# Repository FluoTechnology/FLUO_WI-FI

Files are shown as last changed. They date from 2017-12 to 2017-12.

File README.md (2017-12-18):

<p align="left">

</p>

## FLUO WI-FI

<p align="center">

</p>

[*FLUO WI-FI (V01)*](http://fluotechnology.co.uk/product/fluo-wi-fi/)

The FLUO WI-FI is the best board to to create your own IoT solution. It is a microcontroller board based on the ATmega644p 
by ATMEL (MICROCHIP) that support Arduino Ecosystem and the ESP32 module by ESPRESSIF that enables Wi-Fi and Bluetooth Low Energy (BLE).

Repository Contents
-------------------
* **/Documentation** - Data sheets, Pinout, additional product information
* **/Hardware** - EAGLE design files (.brd, .sch)
* **/Production** - Gerber files
* **/Warranty&Declaration** - Declarations documents and warranty 

License Information
-------------------

This product is _**open source**_! 

Please review the LICENSE.md file for license information. 

If you have any questions or concerns on licensing, please contact support@fluotechnology.co.uk.

Distributed as-is; no warranty is given.

  *With* :heart: *from the FLUO Team.*

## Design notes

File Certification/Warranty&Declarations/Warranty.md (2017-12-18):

##FLUO TECHNOLOGY DECLARATIONS

Fluo Technology products intended for sale and use in worldwide markets comply with the applicable international requirements 
for product safety, electromagnetic compatibility (EMC), essential safety & usage information, WEEE, RoHS, 
quality, and for use in hazardous locations. 
Products delivered into the European Economic Area (EEA) comply with the directives of the European Community (EC). 
Products delivered into North America comply with their respective directives. 
The products bears CE and/or FCC marks which is tested and certified by Arduino to comply with the EC and/or USA directives.

###SAFETY

All boards are labelled with the FCC and CE logo, as they meet the electromagnetic compatibility standards set in 
their respective jurisdictions. Arduino/Genuino products meet the essential requirements 
of EU Directive 2001/95/CE General directive on products safety and Directive 93/68/CE.

###FCC COMPLIANCE

This device complies with Part 15 of the FCC Rules. Operation is subject to the following two conditions: 
(1) this device may not cause harmful interference, and (2) 
this device must accept any interference received, including interference that may cause undesired operation.

###NOTE

This equipment has been tested and found to comply with the limits for a Class B digital device, pursuant 
to part 15 of the FCC Rules. These limits are designed to provide reasonable protection against harmful 
interference in a residential installation. This equipment generates, uses and can radiate radio frequency 
energy and, if not installed and used in accordance with the instructions, may cause harmful interference 
to radio communications. However, there is no guarantee that interference will not occur in a particular 
installation. If this equipment does cause harmful interference to radio or television reception, which can 
be determined by turning the equipment o and on, the user is encouraged to try to correct the interference 
by one or more of the following measures:
→ Reorient or relocate the receiving antenna;
→ Increase the separation between the equipment and receiver;
→ Connect the equipment into an outlet on a circuit different from that to which the receiver is connected;
→ Consult the dealer or an experienced radio/ TV technician for help.
The following parties are responsible for the compliance of radio frequency equipment with the applicable standards: in the case of equipment subject to authorization under the verification procedure, the manufacturer or, in the case of imported equipment, the importer. If subsequent to manufacture and importation, the radio frequency equipment is modified by any party not working under the authority of the responsible party, the party performing the modification becomes the new responsible party.

###TESTING

Products are subject to triple testing to make sure they are not faulty:
→ First, printed circuit boards are thoroughly tested for short circuits and open connections.
→ Then, boards are powered (and, in products containing a microcontroller, the bootloader is programmed) to check there 
are no macroscopic problems preventing the board from turning on.
→ Finally, the most in-depth test: the board is placed into a custom bed of nails tester, 
and programmed by a test program, which checks its overall functionality.
All boards are tested to meet USA and EU consumer safety, health and environmental requirements.

##LIMITED CONVENTIONAL WARRANTY
 
1.1 In addition to the legal warranty provided by the mandatory provisions of the applicable laws,  FLUO Technology hereby conventionally warrants that its products conform to the speciﬁcations indicated on the packaging of the product (the “Specifications”). This conventional warranty lasts for one (1) from the date of the sale.

FLUO Technology shall not be liable for any defects that are caused by neglect, misuse, improper use or mistreatment by the Customer, including improper installation or testing, or for any products that have been altered or modiﬁed in any way by the Customer. Moreover, FLUO Technology shall not be liable for and does not guarantee the results that the Customer intends to obtain by using / installing on other products the design / speciﬁcations of FLUO Technology’s products. Since the products represent an open source to be used by their purchasers for prototyping / designing / developing other products, the testing and other quality control techniques are carried out only to the extent FLUO Technology deems useful.

1.2 In order to be entitled to avail of this conventional warranty, the Customer shall (i) previously raise a claim directly through the website “fluotechnology.co.uk”, (ii) carry out the preliminary checking procedures on the products indicated therein and, if the problem persists, (iii) return the allegedly defective product to the point of sale where the Customer has purchased it:  all the foregoing within the essential terms of fourteen (14) days from the discovery of the alleged defects. If FLUO Technology ascertains that the above procedure has been timely and correctly carried out by the Customer and that the returned products actually fail to conform to the Specifications warranty set forth above and that, therefore, this conventional warranty applies, FLUO Technology's sole liability shall be to replace such products at its sole costs and expenses within a reasonable time. FLUO Technology’s liability shall be limited to products that are determined by FLUO Technology not to conform to  the  Specifications. Replaced products shall be warranted for a new full conventional warranty period.
 
1.3 EXCEPT AS SET FORTH ABOVE, PRODUCTS ARE PROVIDED "AS IS" AND "WITH ALL FAULTS". FLUO Technology DISCLAIMS ALL OTHER CONVENTIONAL WARRANTIES, EXPRESS OR IMPLIED, REGARDING PRODUCTS, INCLUDING, BUT NOT LIMITED TO, ANY IMPLIED WARRANTIES OF MERCHANTABILITY OR FITNESS FOR A PARTICULAR PURPOSE.
 
1.4 The Customer agrees that prior to using any systems that include FLUO Technology products, the Customer  shall test at their own risk and liability such systems and the functionality of the products as used in such systems.
 
FLUO Technology may provide free of charge some suggestions on the technical possibilities, applications or design customization of its products, as well as of the relative  quality characterization, reliability data or other suggestions. The Customer acknowledges and agrees that providing these suggestions shall not expand or otherwise alter FLUO Technology’s warranties, as set forth above, and that no additional obligations or liabilities shall arise from FLUO Technology considering that it providesing such simple suggestions without entering into the merits of the specific uses of its products that each purchaser intends to make.
 
1.5 FLUO Technology products are not authorized nor suitable for use in safety-critical applications where a failure of the FLUO Technology product would reasonably be expected to cause severe personal injury or death. Safety-critical applications include, without limitation, life support devices and systems, equipment or systems for the operation of nuclear facilities and weapons systems. FLUO Technology products are neither designed nor intended for use in military or aerospace applications or environments, nor for automotive applications or the automotive environment. The Customer acknowledges and agrees that any such prohibited use of FLUO Technology products is solely at the Customer’s risk.

1.6 The Customer acknowledges and agrees that the Customer is the sole responsible for compliance with all legal, regulatory and safety-related requirements concerning any use of FLUO Technology products in the Customer’s application, notwithstanding any applications-related information or support that may be provided by FLUO Technology.
 
2. Consequential Damages Waiver.
 
In no event shall FLUO Technology be liable to the Customer or any third parties for any special, collateral,  indirect, punitive, incidental, consequential or exemplary damages in connection with or arising out of the products provided hereunder, regardless of whether FLUO Technology has been advised of the possibility of such damages. This section will survive the termination of the warranty period.

3. Changes to Speciﬁcations.
 
FLUO Technology may make changes to Specifications and products’ descriptions on its website at any time, without notice. Since the products constitute an open source in continuous development and implementation, the Customer must not rely on the absence or characteristics of any features or instructions marked "reserved“ or "undeﬁned". FLUO Technology reserves these for future deﬁnition and shall have no responsibility whatsoever for conﬂicts or incompatibilities arising from future changes to the above. The product information on the website or materials is subject to change without notice. Do not ﬁnalize a product design/technical  specifications with the above said information.

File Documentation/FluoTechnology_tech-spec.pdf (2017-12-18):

Fluo Technology provides a device platforms that enables users to quickly and easily build, connect and control their IoT applications.
We are a young startup company made in UK but with worldwide view.

The Fluo WiFi creates a synergy between
the world of Things and the world of the Internet,
and allows users to interact with it in the way
Vmore simplest possible.

We give the opportunity to people as possible to have access to the world of IoT, and to be able to easily create their own IoT application.

Giving space to their creativity.
Making friendly technologies
Provide them with a product design
Providing them with the latest technology and making it simple. Create a beginner open IoT community.
Allow them to participate in the Industry 4.0 revolution

## Simplifying IoT

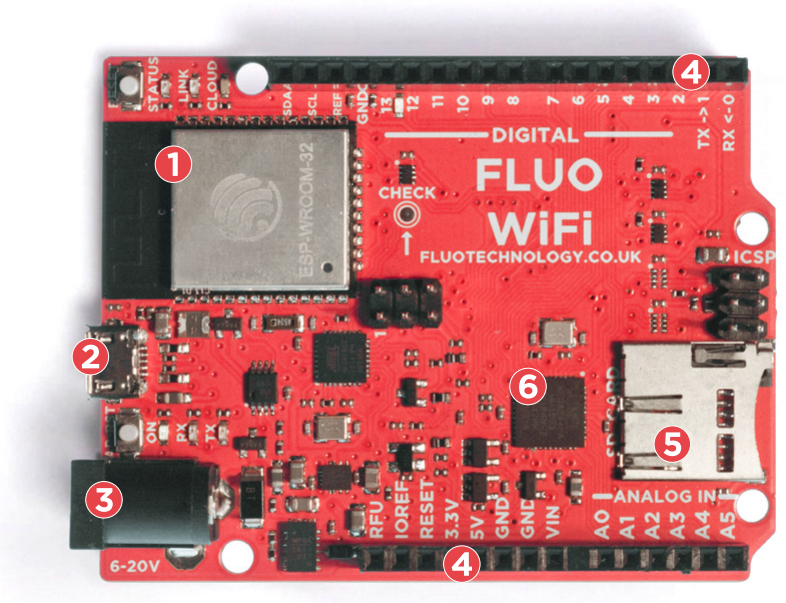
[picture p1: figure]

USB MICRO

POWER Jack 6-20 V

connectors for

arduinio shield r3

sd card
connector

micro controller

wI-FI + BLUETOOTH
LOW ENERGY

2

3

4

5

6

1

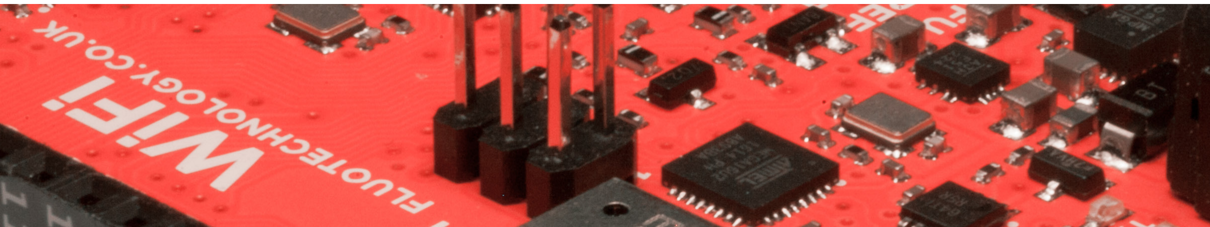
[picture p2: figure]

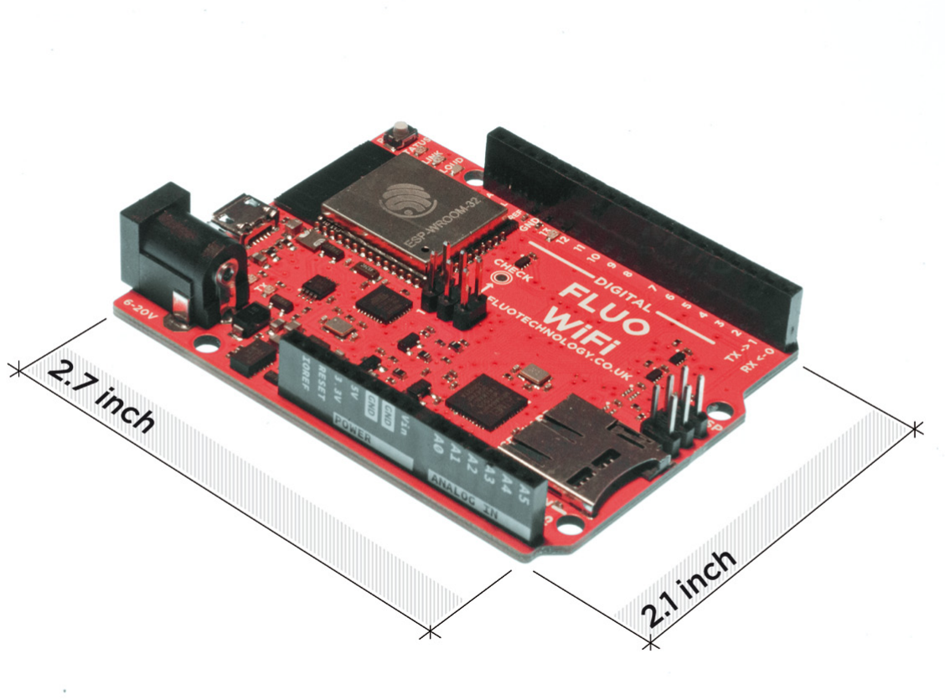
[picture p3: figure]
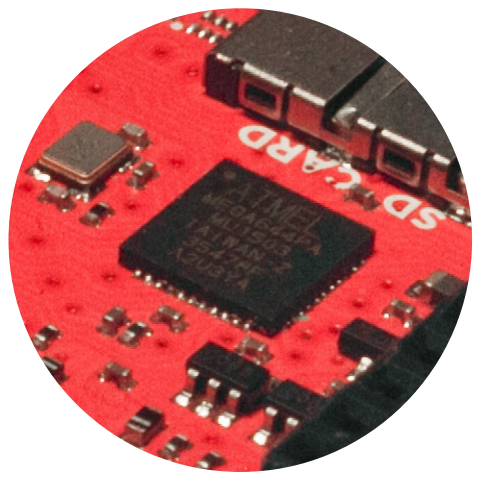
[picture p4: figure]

CPU Name | Atmega 644p

IO MICROCONTROLLER

Architecture | Atmel AVR 8-bit
Core Clock | 16 MHz
SRAM | 4 KBytes
Flash Memory | 64 KBytes
GPIO - Program I/O | 32 (but used only 20)
Interface | SPI-I2C-UART
Operating Voltage | 5V
Connectivity | WiFi 802.11 class BGN/ Bluetooth 4.0 LE

FLUO WiFi TECH SPECS

Wire Interface | USB micro (programmming, debugging, wired connection)
Power IN (real) | 6-20 V
Arduino compatible PIin Headers | R3
Operating Voltage | 5 V
Arduino Shield compatibility | 100%
Power Consumption | 250 mA (estimated)
Size | 2.1”X2.7”
Weight | 0.060 Kg
CPU Name | Espressif esp32

CONNECTIVITY PROCESSOR
(WROOM32 Module)
Architecture | dual core system (Xtensa lx6)
Core Clock | 160 MHz + 160 MHz
SRAM | 520 KB
Flash Memory | 16 MByte
Bluetooth | Legacy and Low Energy
WiFi | 802.11 class BGN

150.0 mbps data rate with ht 40 (49 mhz channel width, 400 ns guard interval, 1 spatial stream, 64-QASM, 5/6 coding rate)

Hardware accelerated encryption (security data)

AES / SHA2 / Elliptical Curve Cryptography / RSA-4096

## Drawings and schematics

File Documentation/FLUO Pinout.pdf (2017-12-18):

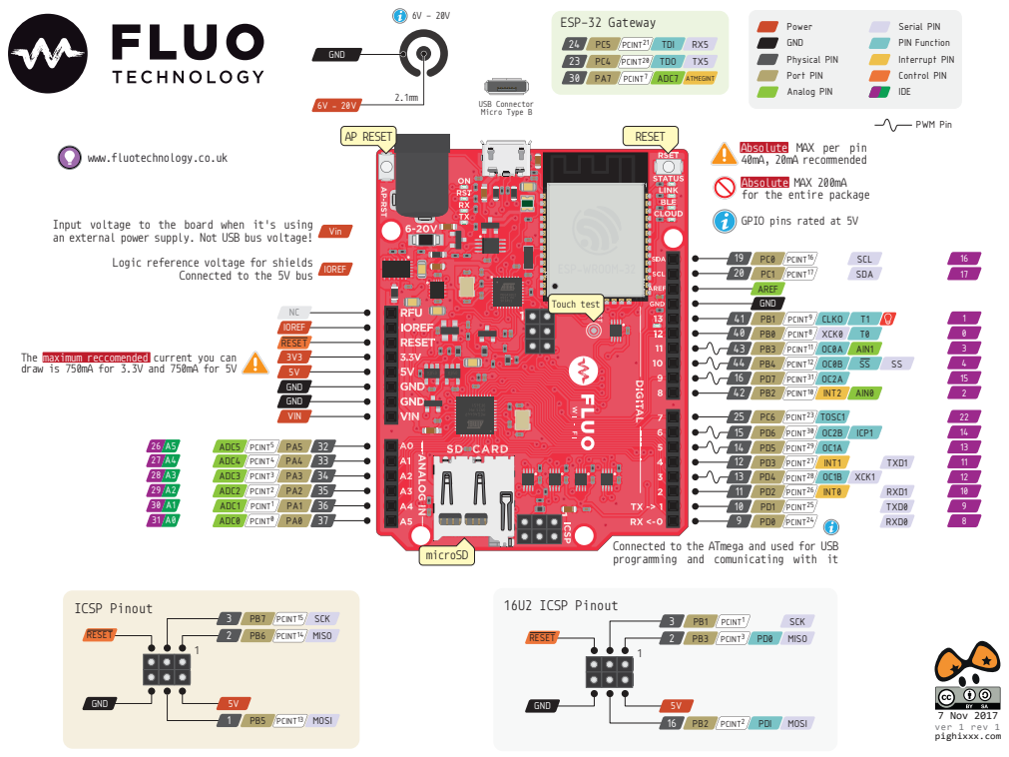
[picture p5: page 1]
GND; USB Connector; Micro Type B; RESET; Touch test; microSD; AP RESET; Vin; IOREF; VIN; PCINT; PA5 ADC5; ADC4 PCINT⁴ PA4 33; PA3 ADC3; PA2 ADC2; PA1 ADC1; PA0 ADC0; PC0 PCINT 19; SCL; PC1 PCINT 20; SDA; AREF; PB1 PCINT 41; PB0 PCINT 40; PD7 PCINT³¹ 16; PB4 PCINT 44; PB2 PCINT 42; 10 INT2 SCK; CLKO XCK0; AIN0; PB3 PCINT 43; 11 OC0A AIN1; ICSP Pinout; PB7 PCINT 3; 15 SCK; PB6 PCINT 2; 14 MISO; PB5 PCINT 1; 13 MOSI; 16U2 ICSP Pinout; PB2 PCINT 16; PDI; MOSI; PB3 PCINT 2; PD0 MISO; PB1 PCINT 3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

Absolute MAX per pin
40mA, 20mA recoended
Absolute MAX 200mA
for the entire package

www.fluotechnology.co.uk

GPIO pins rated at 5V

Input voltage to the board when it's using
an external power supply. Not USB bus voltage!

IOREF Logic reference voltage for shields

Connected to the 5V bus

The maximum reccomended current you can
draw is 750mA for 3.3V and 750mA for 5V

Connected to the ATmega and used for USB
prograing and comunicating with it

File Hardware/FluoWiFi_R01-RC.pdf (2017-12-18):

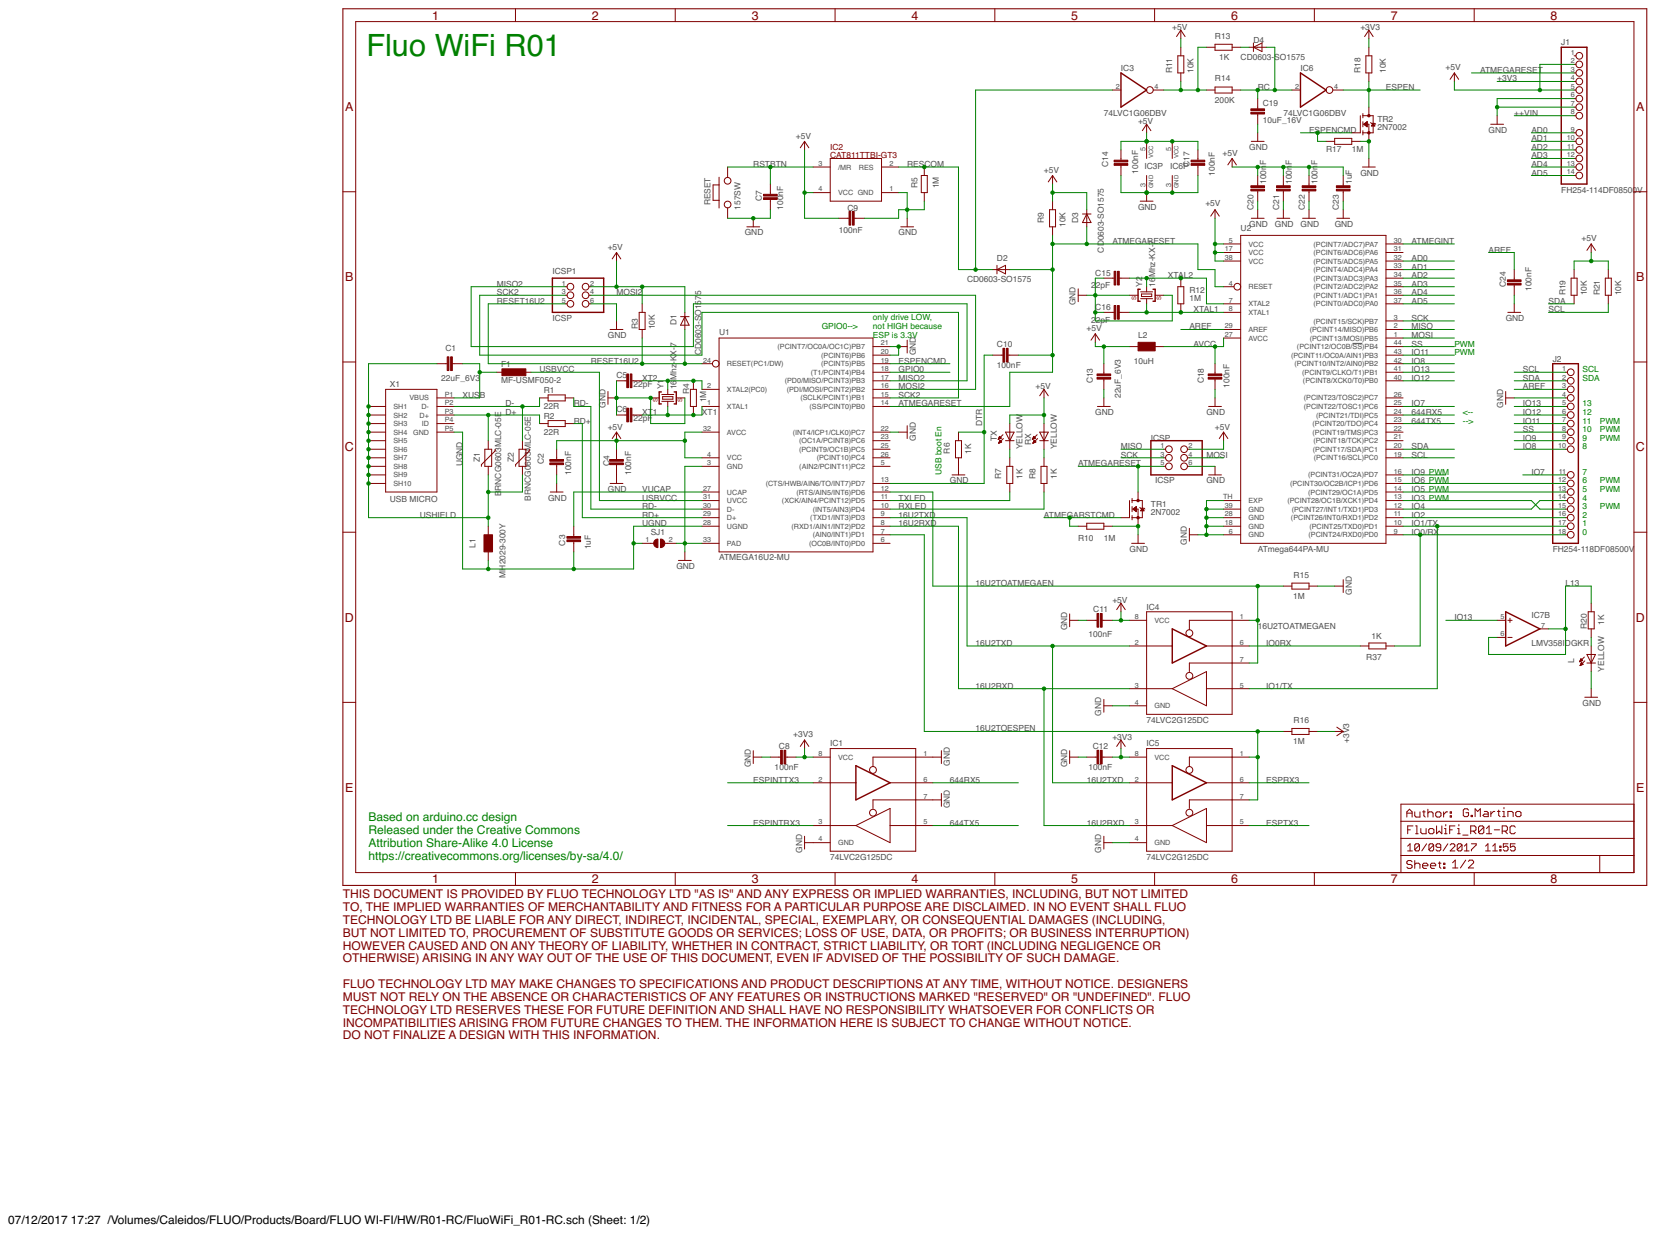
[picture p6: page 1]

only drive LOW, not HIGH because ESP is 3.3V

GND GND

Based on arduino.cc design
Released under the Creative Commons
Attribution Share-Alike 4.0 License
https://creativecommons.org/licenses/by-sa/4.0/

THIS DOCUMENT IS PROVIDED BY FLUO TECHNOLOGY LTD "AS IS" AND ANY EXPRESS OR IMPLIED WARRANTIES, INCLUDING, BUT NOT LIMITED
TO, THE IMPLIED WARRANTIES OF MERCHANTABILITY AND FITNESS FOR A PARTICULAR PURPOSE ARE DISCLAIMED. IN NO EVENT SHALL FLUO
TECHNOLOGY LTD BE LIABLE FOR ANY DIRECT, INDIRECT, INCIDENTAL, SPECIAL, EXEMPLARY, OR CONSEQUENTIAL DAMAGES (INCLUDING, BUT NOT LIMITED TO, PROCUREMENT OF SUBSTITUTE GOODS OR SERVICES; LOSS OF USE, DATA, OR PROFITS; OR BUSINESS INTERRUPTION)

HOWEVER CAUSED AND ON ANY THEORY OF LIABILITY, WHETHER IN CONTRACT, STRICT LIABILITY, OR TORT (INCLUDING NEGLIGENCE OR
OTHERWISE) ARISING IN ANY WAY OUT OF THE USE OF THIS DOCUMENT, EVEN IF ADVISED OF THE POSSIBILITY OF SUCH DAMAGE. FLUO TECHNOLOGY LTD MAY MAKE CHANGES TO SPECIFICATIONS AND PRODUCT DESCRIPTIONS AT ANY TIME, WITHOUT NOTICE. DESIGNERS

MUST NOT RELY ON THE ABSENCE OR CHARACTERISTICS OF ANY FEATURES OR INSTRUCTIONS MARKED "RESERVED" OR "UNDEFINED". FLUO
TECHNOLOGY LTD RESERVES THESE FOR FUTURE DEFINITION AND SHALL HAVE NO RESPONSIBILITY WHATSOEVER FOR CONFLICTS OR
INCOMPATIBILITIES ARISING FROM FUTURE CHANGES TO THEM. THE INFORMATION HERE IS SUBJECT TO CHANGE WITHOUT NOTICE. DO NOT FINALIZE A DESIGN WITH THIS INFORMATION.

07/12/2017 17:27 /Volumes/Caleidos/FLUO/Products/Board/FLUO WI-FI/HW/R01-RC/FluoWiFi_R01-RC.sch (Sheet: 1/2)

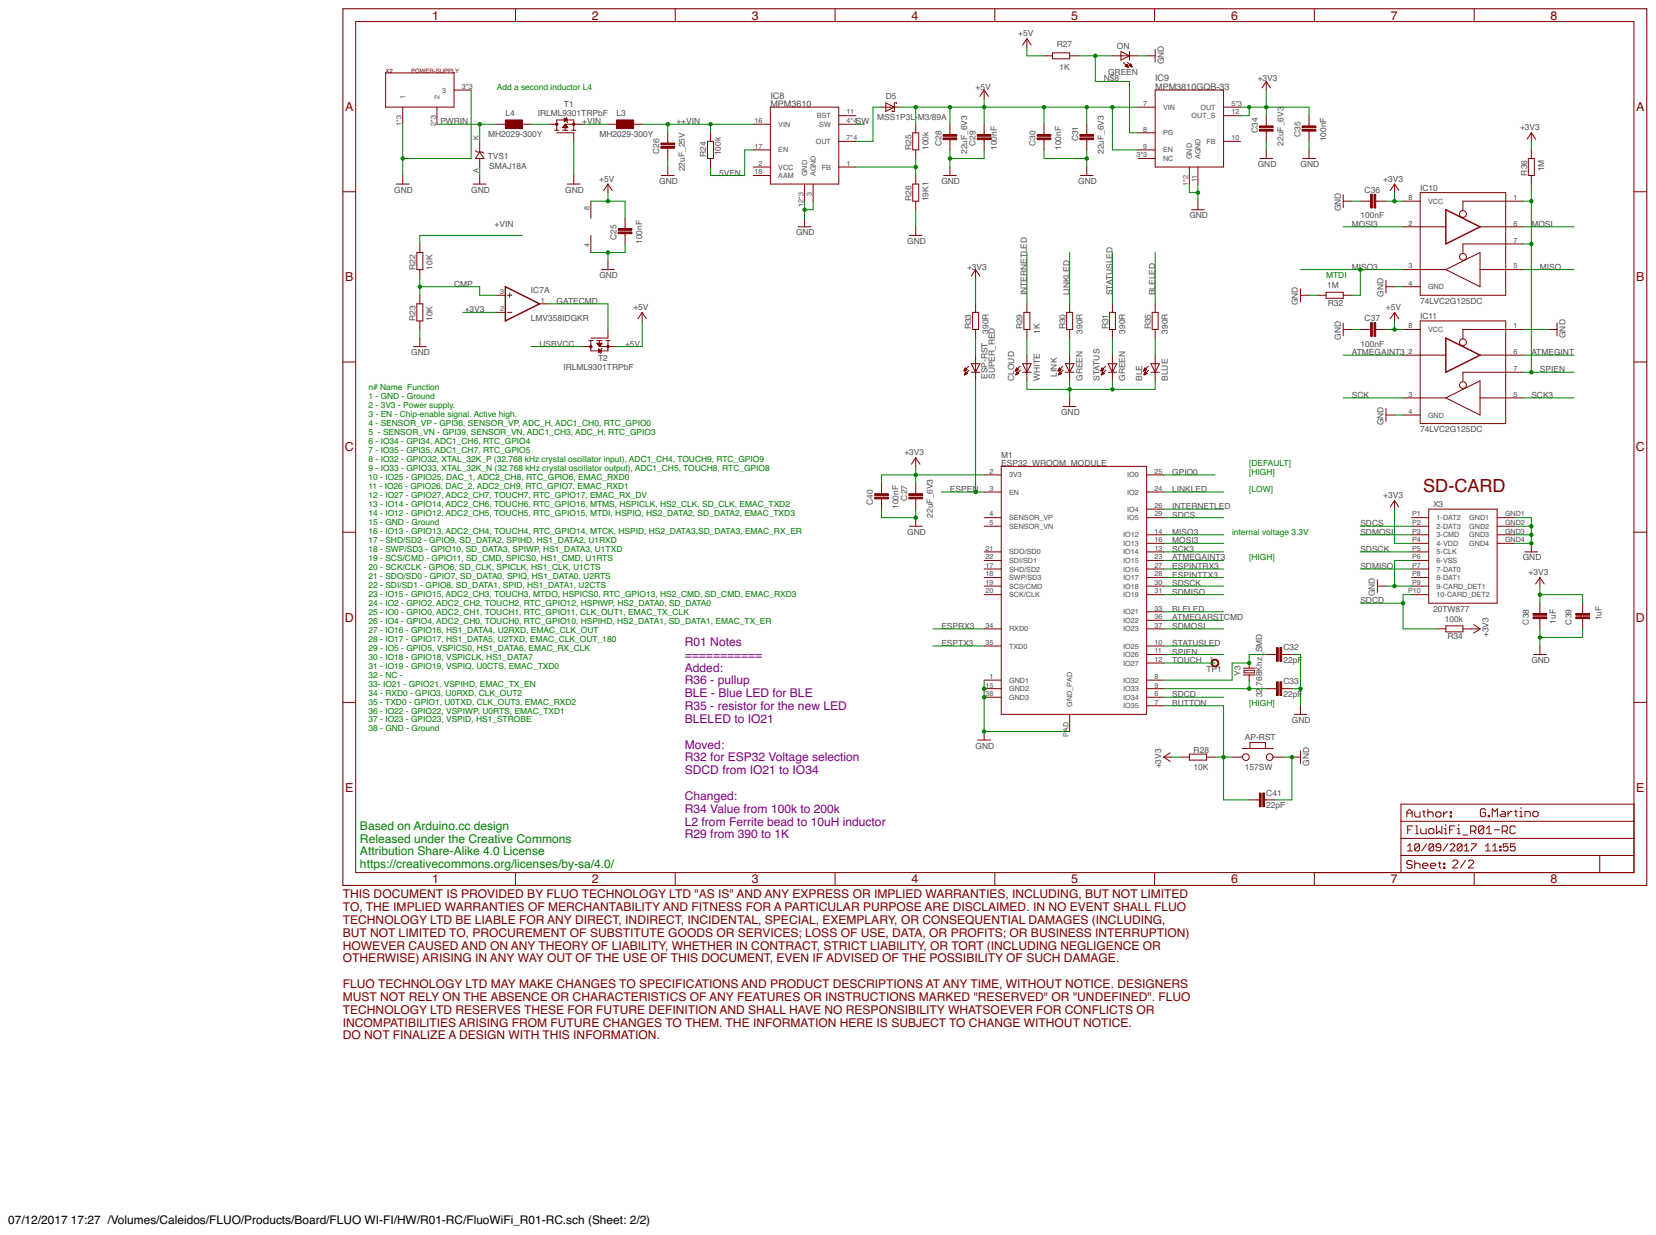
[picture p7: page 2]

GND GND

n# Name Function
1 - GND - Ground
2 - 3V3 - Power supply. 3 - EN - Chip-enable signal. Active high. 4 - SENSOR_VP - GPI36, SENSOR_VP, ADC_H, ADC1_CH0, RTC_GPIO0

R36 - pullup
BLE - Blue LED for BLE
R35 - resistor for the new LED
BLELED to IO21

Changed:
R34 Value from 100k to 200k
L2 from Ferrite bead to 10uH inductor
R29 from 390 to 1K

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

07/12/2017 17:27 /Volumes/Caleidos/FLUO/Products/Board/FLUO WI-FI/HW/R01-RC/FluoWiFi_R01-RC.sch (Sheet: 2/2)

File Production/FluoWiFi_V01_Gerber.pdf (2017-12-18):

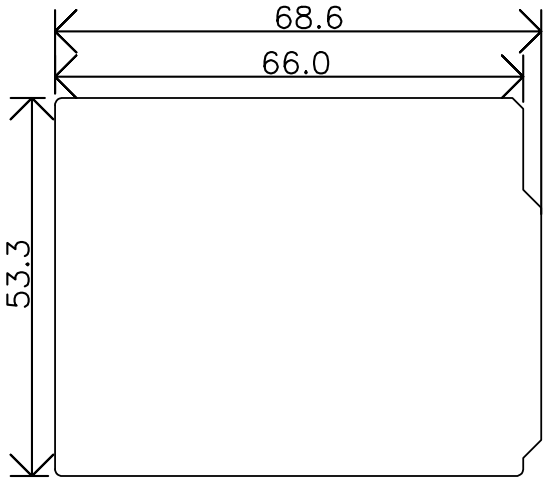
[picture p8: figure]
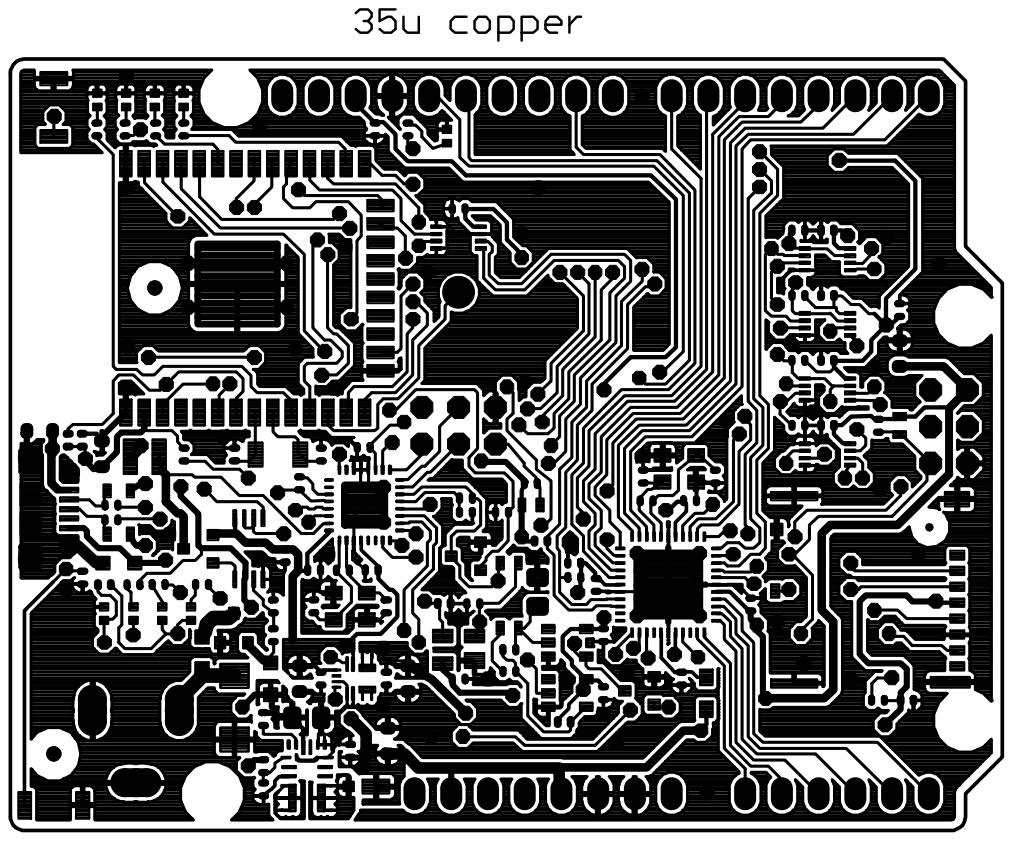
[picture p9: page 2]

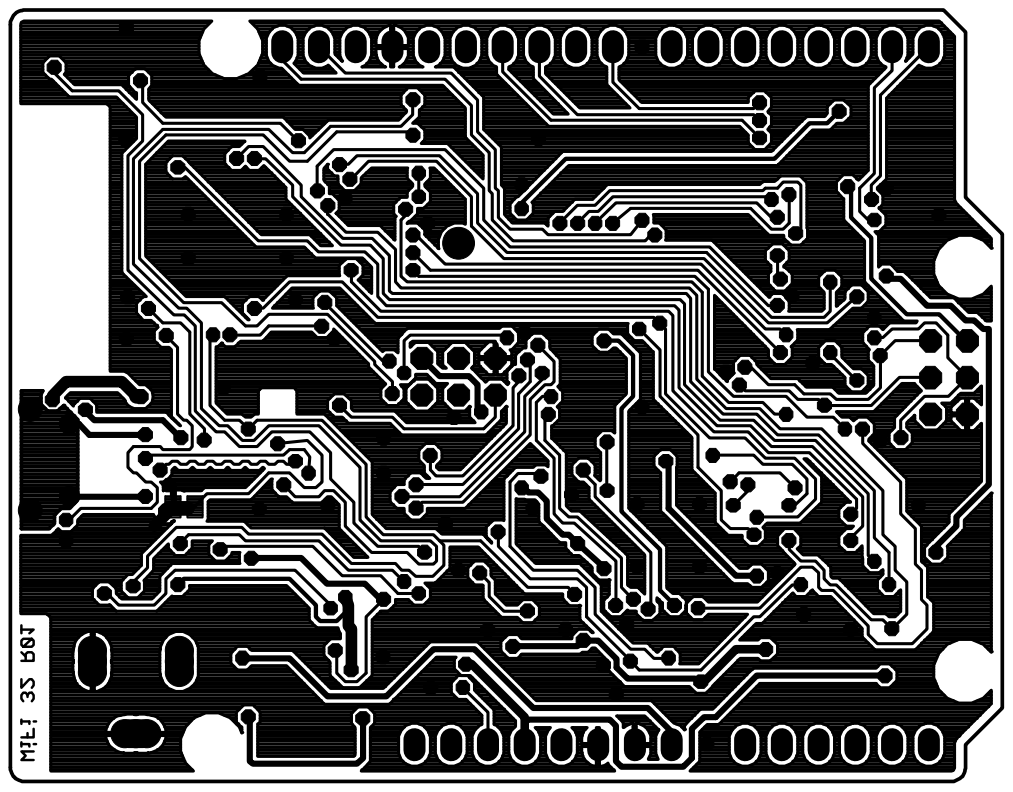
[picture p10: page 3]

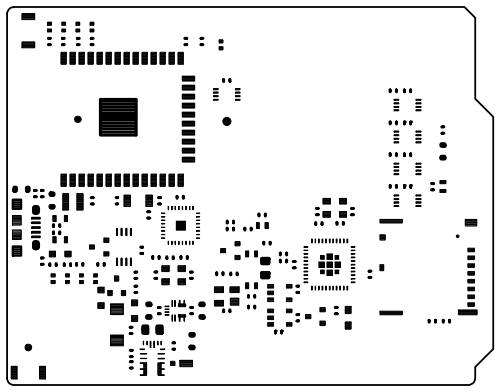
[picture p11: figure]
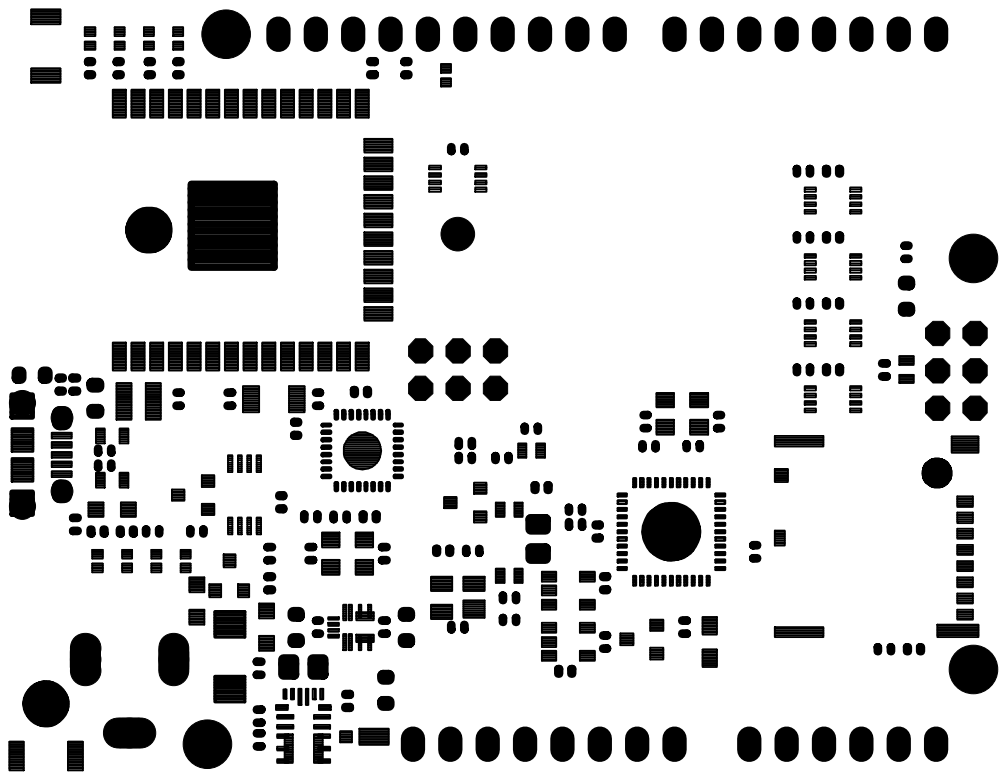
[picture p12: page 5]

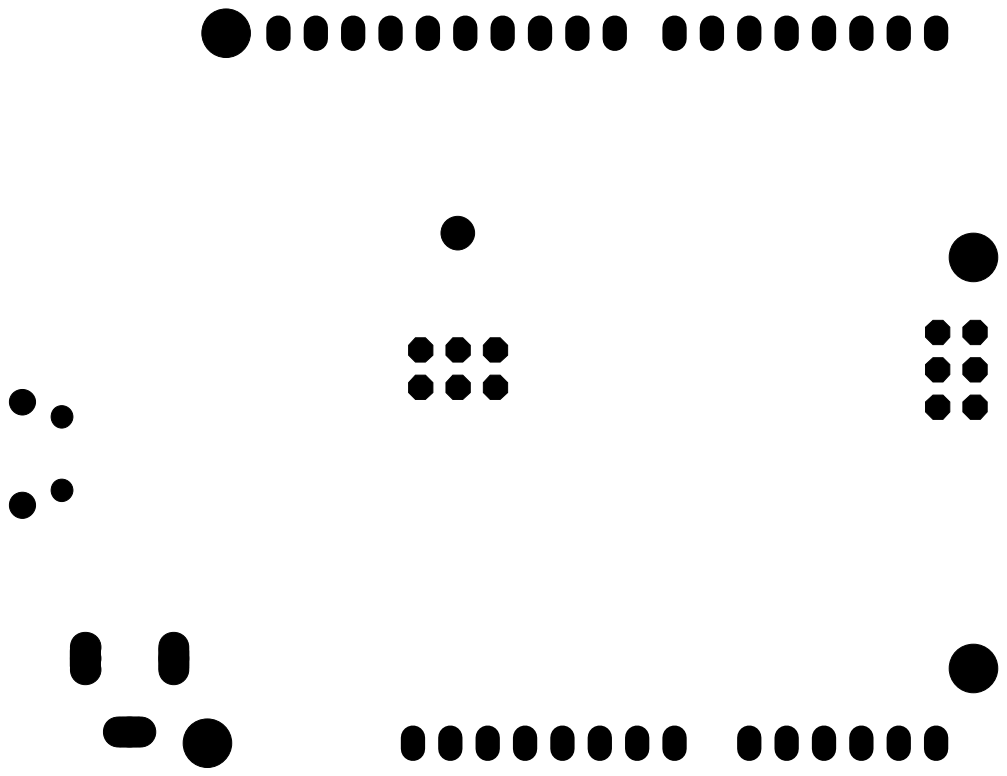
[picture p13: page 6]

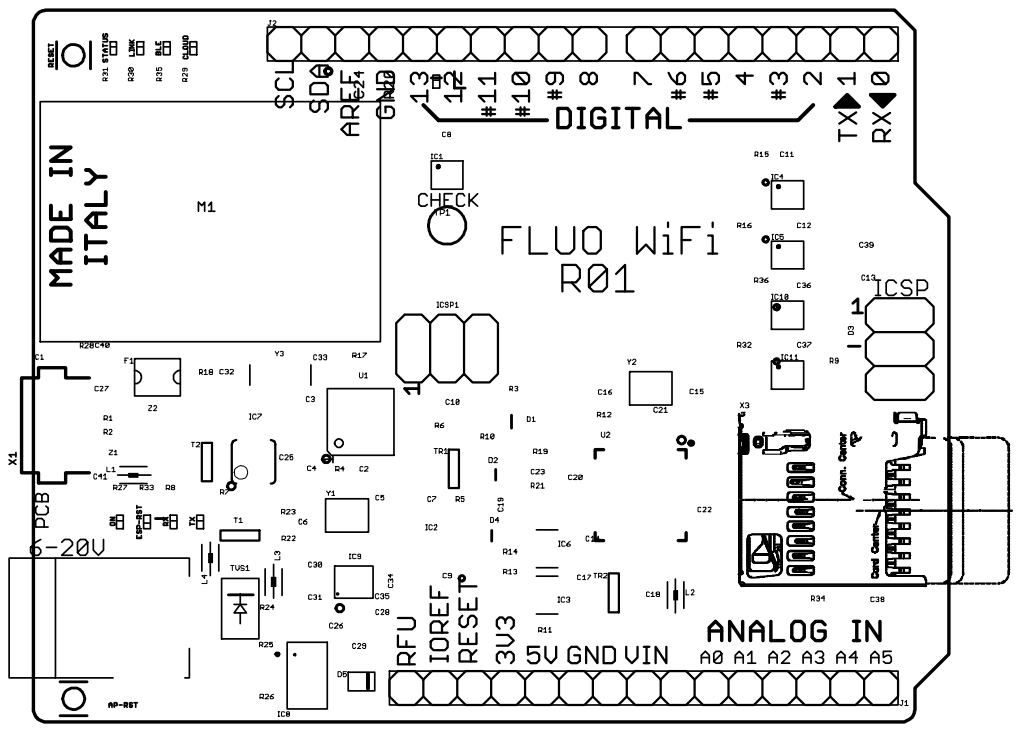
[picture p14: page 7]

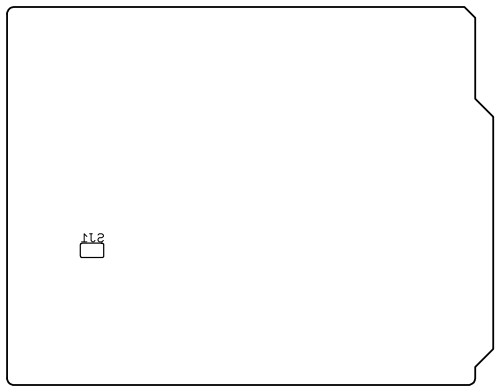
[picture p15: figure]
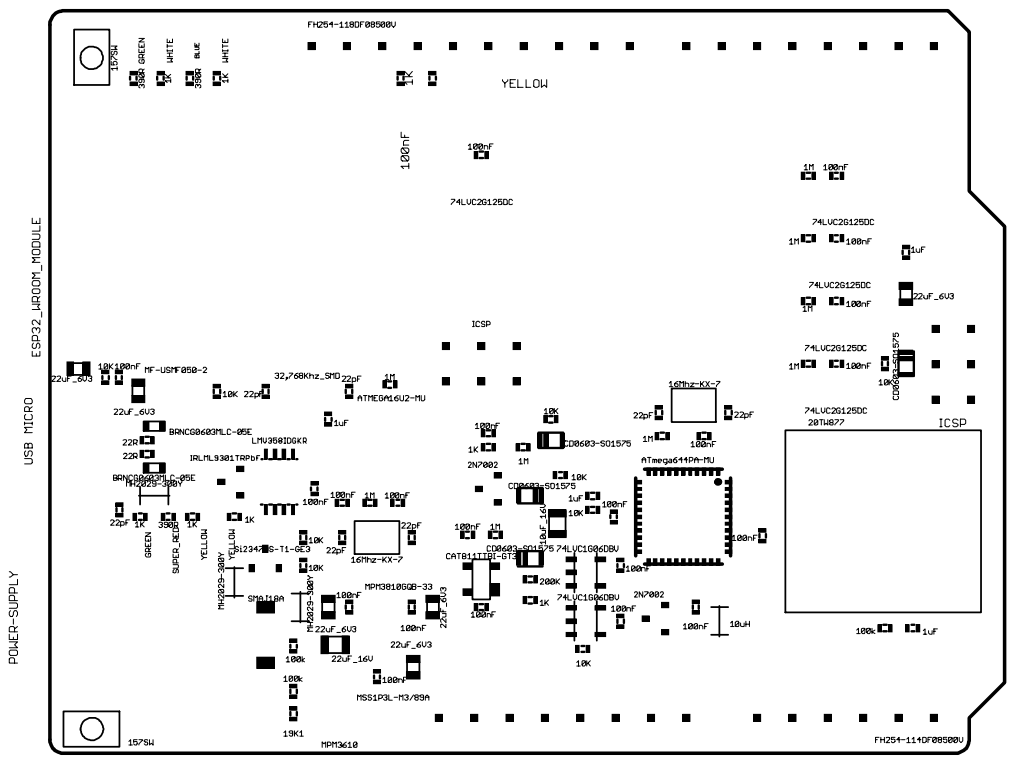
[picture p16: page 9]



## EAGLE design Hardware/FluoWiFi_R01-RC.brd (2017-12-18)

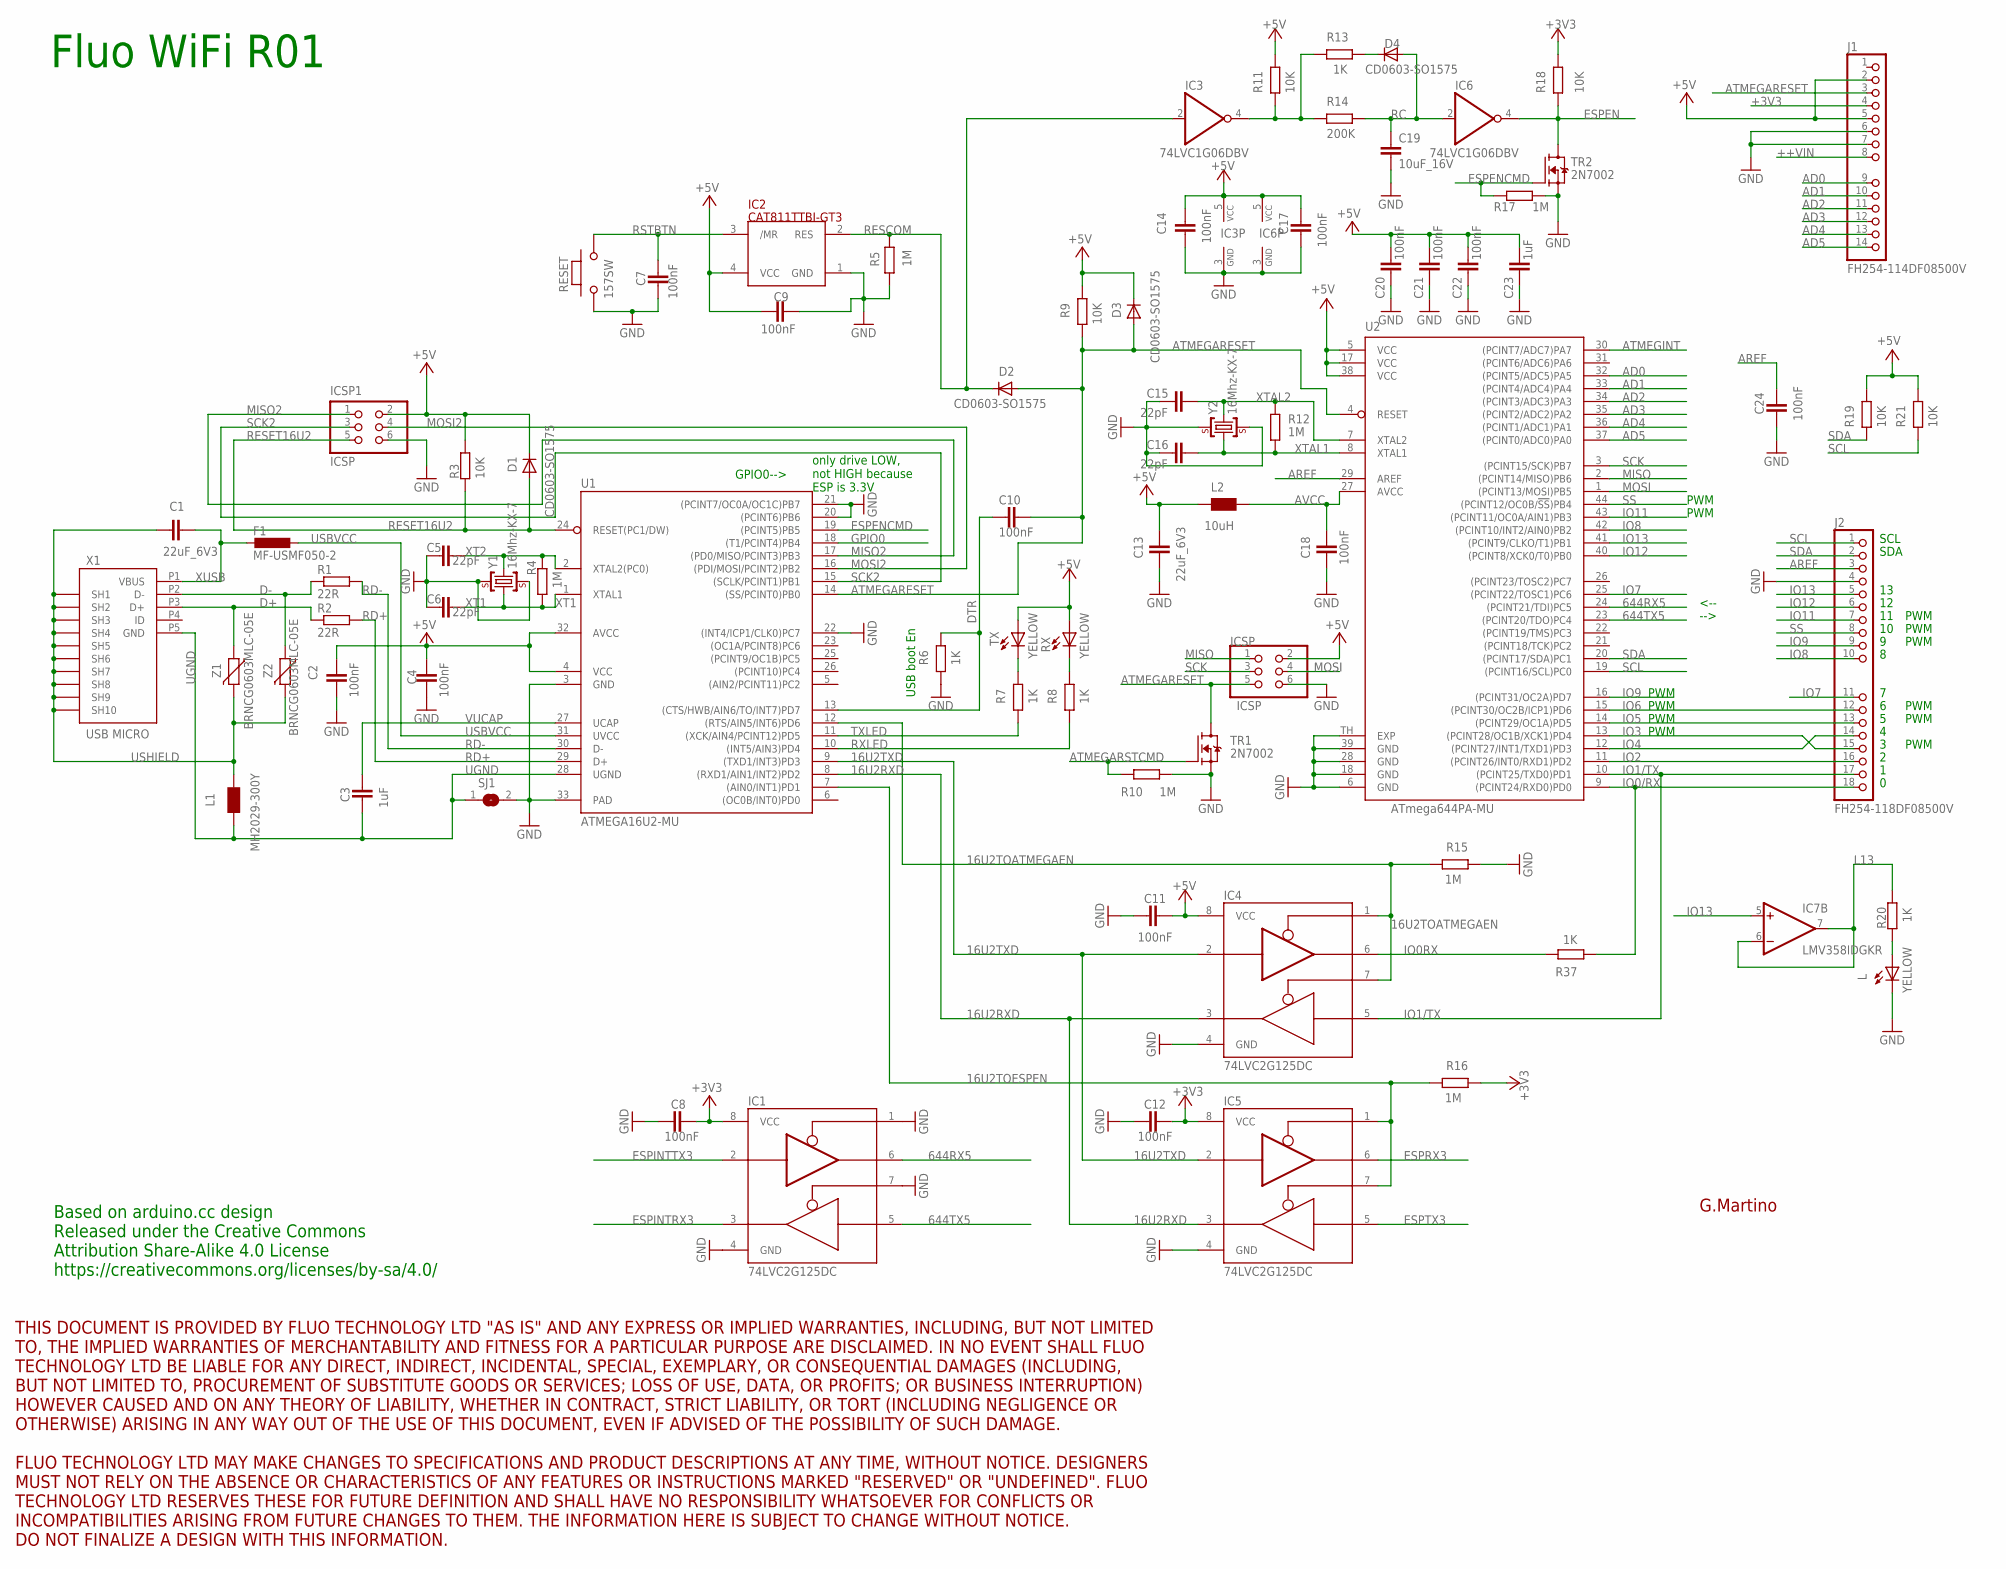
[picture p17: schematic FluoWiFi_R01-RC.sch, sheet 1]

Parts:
C1, C13: 22uF_6V3; C0603-ROUND
C2, C4, C7, C8, C9, C10, C11, C12, C14, C17, C18, C20, C21, C22, C24: 100nF; C0402
C3, C23: 1uF; C0402
C5, C6, C15, C16: 22pF; C0402
C19: 10uF_16V; C0805_ROUND
D1, D2, D3, D4: CD0603-SO1575; 0603
F1: MF-USMF050-2; 1210
IC1, IC4, IC5: 74LVC2G125DC; VSSOP8
IC2: CAT811TTBI-GT3; SOT143
IC3, IC6: 74LVC1G06DBV; SOT23-5
IC7: LMV358IDGKR; MSOP08
ICSP, ICSP1: ICSP; 2X03
J1: FH254-114DF08500V; 1-14-TH-PRESSFIT
J2: FH254-118DF08500V; 1X18-TH-PRESSFIT
L: YELLOW; 0402_CHIP_LED
L1: MH2029-300Y; 0805
L2: 10uH; 0805
R1, R2: 22R; R0402
R3, R9, R11, R18, R19, R21: 10K; R0402
R4, R5, R10, R12, R15, R16, R17: 1M; R0402
R6, R7, R8, R13, R20, R37: 1K; R0402
R14: 200K; R0402
RESET: 157SW; SMD_157SW
RX: YELLOW; 0402_CHIP_LED
SJ1: SJSJ_NO_RESIST; SJ_NO_RESIST
TR1, TR2: 2N7002; SOT-23
TX: YELLOW; 0402_CHIP_LED
U1: ATMEGA16U2-MU; MLF32
U2: ATmega644PA-MU; VQFN44
U$1: DISCLAIMER-FLUO
X1: USB MICRO; CON2_USB_MICRO_B_AT_HOLES
Y1, Y2: 16Mhz-KX-7; CRYSTAL-3.2-2.5
Z1, Z2: BRNCG0603MLC-05E; CT/CN0603

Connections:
16U2RXD: IC4.3 (2Y), IC5.3 (2Y), U1.8 ((RXD1/AIN1/INT2)PD2)
16U2TOATMEGAEN: IC4.1 (OE1), IC4.7 (OE2), R15.2, U1.12 ((RTS/AIN5/INT6)PD6)
16U2TOESPEN: IC5.1 (OE1), IC5.7 (OE2), R16.2, U1.7 ((AIN0/INT1)PD1)
16U2TXD: IC4.2 (1A), IC5.2 (1A), U1.9 ((TXD1/INT3)PD3)
644RX5: IC1.6 (1Y), U2.24 ((PCINT21/TDI)PC5)
644TX5: IC1.5 (2A), U2.23 ((PCINT20/TDO)PC4)
+3V3: C8.2, C12.1, IC1.8 (VCC), IC5.8 (VCC), J1.4, R16.1, R18.2; also elsewhere on the board
+5V: C2.1, C4.2, C9.1, C11.1, C13.2, C14.2, C17.2, C20.2, C21.2, C22.2, C23.1, D1.C, D3.C, IC2.4 (VCC), IC3.5 (VCC), IC4.8 (VCC), IC6.5 (VCC), ICSP.2, ICSP1.2, J1.2, J1.5, L2.1, R3.2, R9.2, R11.2, R19.2, R21.2, RX.A, TX.A, U1.4 (VCC), U1.32 (AVCC), U2.5 (VCC), U2.17 (VCC), U2.38 (VCC); also elsewhere on the board
++VIN: J1.8; also elsewhere on the board
AD0: J1.9, U2.32 ((PCINT5/ADC5)PA5)
AD1: J1.10, U2.33 ((PCINT4/ADC4)PA4)
AD2: J1.11, U2.34 ((PCINT3/ADC3)PA3)
AD3: J1.12, U2.35 ((PCINT2/ADC2)PA2)
AD4: J1.13, U2.36 ((PCINT1/ADC1)PA1)
AD5: J1.14, U2.37 ((PCINT0/ADC0)PA0)
AREF: C24.2, J2.3, U2.29 (AREF)
ATMEGARESET: C10.2, D2.A, D3.A, ICSP.5, J1.3, R9.1, TR1.3 (D), U1.14 ((SS/PCINT0)PB0), U2.4 (RESET)
ATMEGARSTCMD: R10.1, TR1.1 (G); also elsewhere on the board
ATMEGINT: U2.30 ((PCINT7/ADC7)PA7); also elsewhere on the board
AVCC: C18.2, L2.2, U2.27 (AVCC)
D+: R2.1, X1.P3 (D+), Z1.1
D-: R1.1, X1.P2 (D-), Z2.1
DTR: C10.1, R6.2, U1.13 ((CTS/HWB/AIN6/TO/INT7)PD7)
ESPEN: IC6.4 (O), R18.1, TR2.3 (D); also elsewhere on the board
ESPENCMD: R17.1, TR2.1 (G), U1.19 ((PCINT5)PB5)
ESPINTRX3: IC1.3 (2Y); also elsewhere on the board
ESPINTTX3: IC1.2 (1A); also elsewhere on the board
ESPRX3: IC5.6 (1Y); also elsewhere on the board
ESPTX3: IC5.5 (2A); also elsewhere on the board
GND: C2.2, C4.1, C5.2, C6.2, C7.1, C8.1, C9.2, C11.2, C12.2, C13.1, C14.1, C15.2, C16.2, C17.1, C18.1, C19.2, C20.1, C21.1, C22.1, C23.2, C24.1, IC1.1 (OE1), IC1.4 (GND), IC1.7 (OE2), IC2.1 (GND), IC3.3 (GND), IC4.4 (GND), IC5.4 (GND), IC6.3 (GND), ICSP.6, ICSP1.6, J1.6, J1.7, J2.4, L.C, R5.1, R6.1, R10.2, R15.1, R17.2, RESET.1, SJ1.2, TR1.2 (S), TR2.2 (S), U1.3 (GND), U1.20 ((PCINT6)PB6), U1.21 ((PCINT7/OC0A/OC1C)PB7), U1.22 ((INT4/ICP1/CLK0)PC7), U1.33 (PAD), U2.6 (GND), U2.18 (GND), U2.28 (GND), U2.39 (GND), U2.TH (EXP), Y1.2 (GND), Y1.4 (GND), Y2.2 (GND), Y2.4 (GND); also elsewhere on the board
GPIO0: U1.18 ((T1/PCINT4)PB4); also elsewhere on the board
IO0/RX: J2.18, R37.1, U2.9 ((PCINT24/RXD0)PD0)
IO0RX: IC4.6 (1Y), R37.2
IO1/TX: IC4.5 (2A), J2.17, U2.10 ((PCINT25/TXD0)PD1)
IO2: J2.16, U2.11 ((PCINT26/INT0/RXD1)PD2)
IO3: J2.15, U2.13 ((PCINT28/OC1B/XCK1)PD4)
IO4: J2.14, U2.12 ((PCINT27/INT1/TXD1)PD3)
IO5: J2.13, U2.14 ((PCINT29/OC1A)PD5)
IO6: J2.12, U2.15 ((PCINT30/OC2B/ICP1)PD6)
IO7: J2.11, U2.25 ((PCINT22/TOSC1)PC6)
IO8: J2.10, U2.42 ((PCINT10/INT2/AIN0)PB2)
IO9: J2.9, U2.16 ((PCINT31/OC2A)PD7)
IO11: J2.7, U2.43 ((PCINT11/OC0A/AIN1)PB3)
IO12: J2.6, U2.40 ((PCINT8/XCK0/T0)PB0)
IO13: IC7.5 (+IN), J2.5, U2.41 ((PCINT9/CLKO/T1)PB1)
L13: IC7.6 (-IN), IC7.7 (OUT), R20.2
MISO: ICSP.1, U2.2 ((PCINT14/MISO)PB6); also elsewhere on the board
MISO2: ICSP1.1, U1.17 ((PD0/MISO/PCINT3)PB3)
MOSI: ICSP.4, U2.1 ((PCINT13/MOSI)PB5); also elsewhere on the board
MOSI2: ICSP1.4, U1.16 ((PDI/MOSI/PCINT2)PB2)
unnamed: IC3.4 (O), R11.1, R13.1, R14.2
unnamed: D4.C, R13.2
unnamed: R7.2, TX.C
unnamed: R8.2, RX.C
unnamed: L.A, R20.1
RC: C19.1, D4.A, IC6.2 (I), R14.1
RD+: R2.2, U1.29 (D+)
RD-: R1.2, U1.30 (D-)
RESCOM: D2.C, IC2.2 (RES), IC3.2 (I), R5.2
RESET16U2: D1.A, ICSP1.5, R3.1, U1.24 (RESET(PC1/DW))
RSTBTN: C7.2, IC2.3 (/MR), RESET.2
RXLED: R8.1, U1.10 ((INT5/AIN3)PD4)
SCK: ICSP.3, U2.3 ((PCINT15/SCK)PB7); also elsewhere on the board
SCK2: ICSP1.3, U1.15 ((SCLK/PCINT1)PB1)
SCL: J2.1, R21.1, U2.19 ((PCINT16/SCL)PC0)
SDA: J2.2, R19.1, U2.20 ((PCINT17/SDA)PC1)
SS: J2.8, U2.44 ((PCINT12/OC0B/!SS!)PB4)
TXLED: R7.1, U1.11 ((XCK/AIN4/PCINT12)PD5)
UGND: C3.2, L1.1, SJ1.1, U1.28 (UGND), X1.P5 (GND)
USBVCC: F1.1, U1.31 (UVCC); also elsewhere on the board
USHIELD: C1.2, L1.2, X1.P$2 (SH7), X1.P$3 (SH8), X1.P$6 (SH9), X1.P$7 (SH10), X1.S1 (SH1), X1.S2 (SH2), X1.S3 (SH3), X1.S4 (SH4), X1.S5 (SH5), X1.S6 (SH6), Z1.2, Z2.2
VUCAP: C3.1, U1.27 (UCAP)
XT1: C6.1, R4.1, U1.1 (XTAL1), Y1.1 (C1)
XT2: C5.1, R4.2, U1.2 (XTAL2(PC0)), Y1.3 (C2)
XTAL1: C16.1, R12.1, U2.8 (XTAL1), Y2.1 (C1)
XTAL2: C15.1, R12.2, U2.7 (XTAL2), Y2.3 (C2)
XUSB: C1.1, F1.2, X1.P1 (VBUS)

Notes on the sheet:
Fluo WiFi R01
USB boot En
SDA
SCL
G.Martino
PWM
-->
<--
only drive LOW, not HIGH because ESP is 3.3V
GPIO0-->
Based on arduino.cc design Released under the Creative Commons Attribution Share-Alike 4.0 License https://creativecommons.org/licenses/by-sa/4.0/

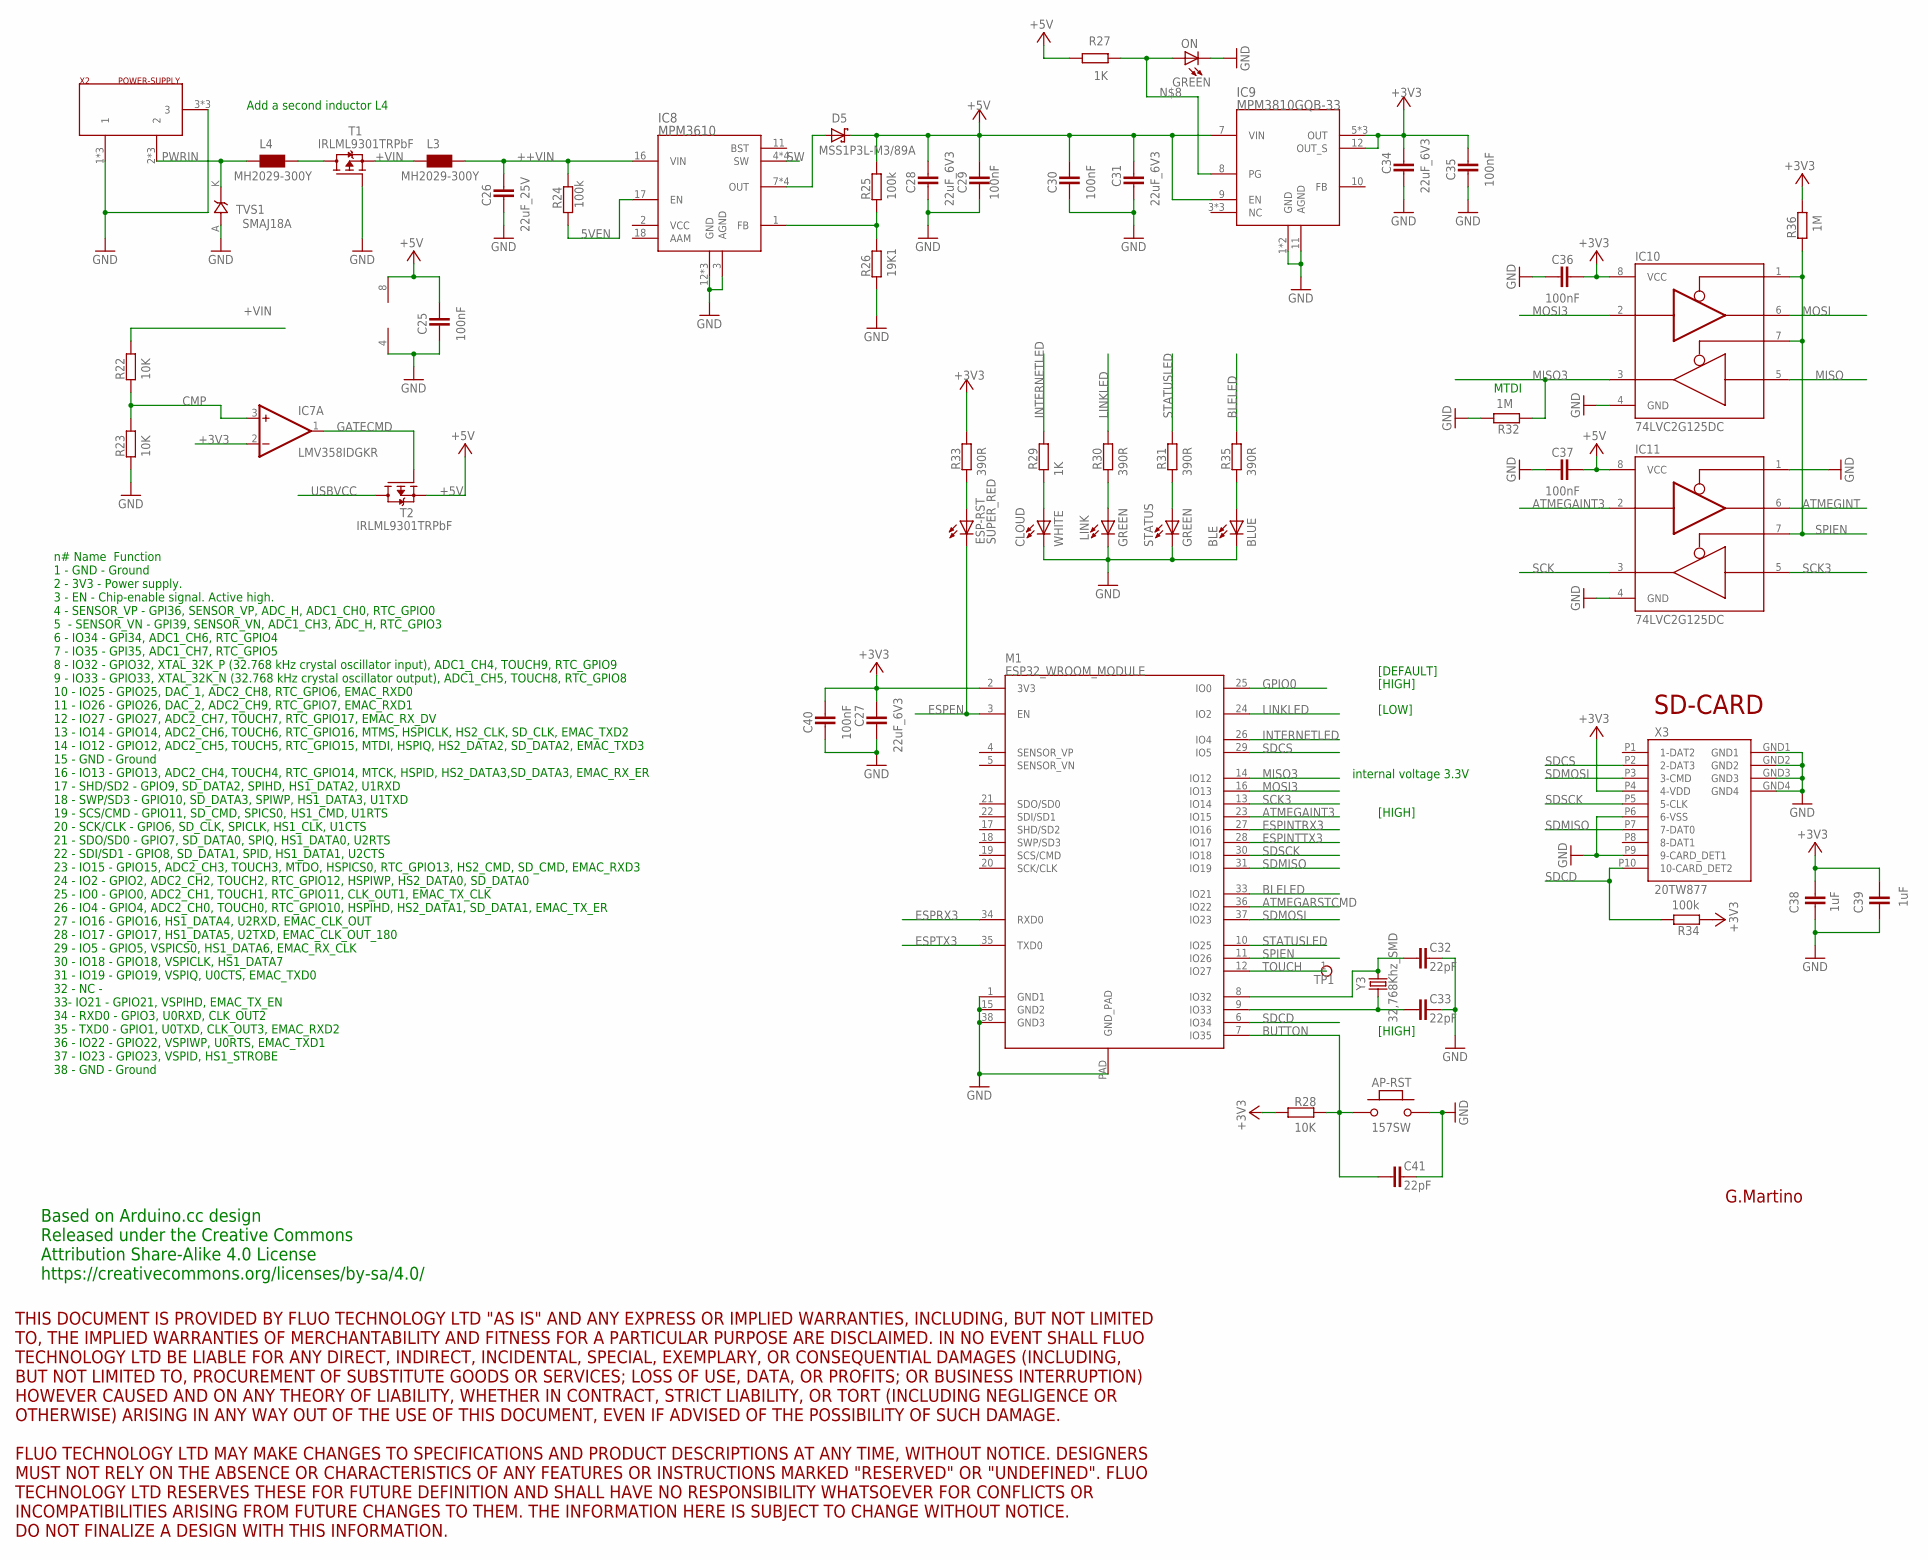
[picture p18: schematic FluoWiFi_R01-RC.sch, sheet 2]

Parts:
AP-RST: 157SW; SMD_157SW
BLE: BLUE; 0402_CHIP_LED
C25, C29, C30, C35, C36, C37, C40: 100nF; C0402
C26: 22uF_25V; C0805_ROUND
C27, C28, C31, C34: 22uF_6V3; C0603-ROUND
C32, C33, C41: 22pF; C0402
C38, C39: 1uF; C0402
CLOUD: WHITE; 0402_CHIP_LED
D5: MSS1P3L-M3/89A; MICROSMP
ESP-RST: SUPER_RED; 0402_CHIP_LED
IC7: LMV358IDGKR; MSOP08
IC8: MPM3610; QFN-20
IC9: MPM3810GQB-33; QFN-12
IC10, IC11: 74LVC2G125DC; VSSOP8
L3, L4: MH2029-300Y; 0805
LINK: GREEN; 0402_CHIP_LED
M1: ESP32_WROOM_MODULE; WROOM_ESP32
ON: GREEN; 0402_CHIP_LED
R22, R23, R28: 10K; R0402
R24, R25, R34: 100k; R0402
R26: 19K1; R0402
R27, R29: 1K; R0402
R30, R31, R33, R35: 390R; R0402
R32, R36: 1M; R0402
STATUS: GREEN; 0402_CHIP_LED
T1, T2: IRLML9301TRPbF; SOT-23
TP1: XXXX_TEST-POINTS_50; TEST_50
TVS1: SMAJ18A; SMA-TVS
U$2: DISCLAIMER-FLUO
X2: POWER-SUPPLY; POWERSUPPLY_DC-21MM
X3: 20TW877; 20TW877_CARD_CONNECTOR
Y3: 32,768Khz_SMD; RESONATOR_EPSON_FC_145

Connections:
5VEN: IC8.17 (EN), R24.2
+3V3: C27.1, C34.1, C35.2, C36.1, C38.2, C39.2, C40.2, IC7.2 (-IN), IC9.5 (OUT), IC9.6 (OUT), IC9.12 (OUT_S), IC9.14 (OUT), IC10.8 (VCC), M1.2 (3V3), R28.2, R33.2, R34.1, R36.1, X3.P4 (4-VDD); also elsewhere on the board
+5V: C25.2, C28.1, C29.1, C30.1, C31.1, C37.1, D5.K (C), IC7.8 (V+), IC9.7 (VIN), IC9.9 (EN), IC11.8 (VCC), R25.2, R27.2, T2.2 (S); also elsewhere on the board
+5V_SEZ: D5.A, IC8.7 (OUT), IC8.8 (OUT), IC8.9 (OUT), IC8.20 (OUT)
++VIN: C26.1, IC8.16 (VIN), L3.2, R24.1; also elsewhere on the board
+VIN: L3.1, R22.2, T1.2 (S)
ATMEGAINT3: IC11.2 (1A), M1.23 (IO15)
ATMEGARSTCMD: M1.36 (IO22); also elsewhere on the board
ATMEGINT: IC11.6 (1Y); also elsewhere on the board
BLELED: M1.33 (IO21), R35.2
BUTTON: AP-RST.1, C41.1, M1.7 (IO35), R28.1
CMP: IC7.3 (+IN), R22.1, R23.2
ESPEN: ESP-RST.C, M1.3 (EN); also elsewhere on the board
ESPINTRX3: M1.27 (IO16); also elsewhere on the board
ESPINTTX3: M1.28 (IO17); also elsewhere on the board
ESPRX3: M1.34 (RXD0); also elsewhere on the board
ESPTX3: M1.35 (TXD0); also elsewhere on the board
GATECMD: IC7.1 (OUT), T2.1 (G)
GND: AP-RST.2, BLE.C, C25.1, C26.2, C27.2, C28.2, C29.2, C30.2, C31.2, C32.2, C33.2, C34.2, C35.1, C36.2, C37.2, C38.1, C39.1, C40.1, C41.2, CLOUD.C, IC7.4 (V-), IC8.3 (AGND), IC8.12 (GND), IC8.13 (GND), IC8.14 (GND), IC9.1 (GND), IC9.2 (GND), IC9.11 (AGND), IC10.4 (GND), IC11.1 (OE1), IC11.4 (GND), LINK.C, M1.1 (GND1), M1.15 (GND2), M1.38 (GND3), M1.PAD (GND_PAD), ON.C, R23.1, R26.1, R32.1, STATUS.C, T1.1 (G), TVS1.A, X2.1, X2.3, X2.4 (1), X2.5 (1), X2.6 (3), X2.7 (3), X3.GND1, X3.GND2, X3.GND3, X3.GND4, X3.P6 (6-VSS), X3.P9 (9-CARD_DET1); also elsewhere on the board
GPIO0: M1.25 (IO0); also elsewhere on the board
INTERNETLED: M1.26 (IO4), R29.2
LINKLED: M1.24 (IO2), R30.2
MISO: IC10.5 (2A); also elsewhere on the board
MISO3: IC10.3 (2Y), M1.14 (IO12), R32.2
MOSI: IC10.6 (1Y); also elsewhere on the board
MOSI3: IC10.2 (1A), M1.16 (IO13)
unnamed: ESP-RST.A, R33.1
unnamed: L4.2, T1.3 (D)
unnamed: BLE.A, R35.1
unnamed: CLOUD.A, R29.1
unnamed: IC9.8 (PG), ON.A, R27.1
unnamed: C32.1, M1.8 (IO32), Y3.P$2 (2)
unnamed: C33.1, M1.9 (IO33), Y3.P$1 (1)
unnamed: LINK.A, R30.1
unnamed: R31.1, STATUS.A
unnamed: IC8.1 (FB), R25.1, R26.2
PWRIN: L4.1, TVS1.K, X2.2, X2.8 (2), X2.9 (2)
SCK: IC11.3 (2Y); also elsewhere on the board
SCK3: IC11.5 (2A), M1.13 (IO14)
SDCD: M1.6 (IO34), R34.2, X3.P10 (10-CARD_DET2)
SDCS: M1.29 (IO5), X3.P2 (2-DAT3)
SDMISO: M1.31 (IO19), X3.P7 (7-DAT0)
SDMOSI: M1.37 (IO23), X3.P3 (3-CMD)
SDSCK: M1.30 (IO18), X3.P5 (5-CLK)
SPIEN: IC10.1 (OE1), IC10.7 (OE2), IC11.7 (OE2), M1.11 (IO26), R36.2
STATUSLED: M1.10 (IO25), R31.2
SW: IC8.4 (SW), IC8.5 (SW), IC8.6 (SW), IC8.19 (SW)
TOUCH: M1.12 (IO27), TP1.1
USBVCC: T2.3 (D); also elsewhere on the board

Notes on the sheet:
n# Name Function 1 - GND - Ground 2 - 3V3 - Power supply. 3 - EN - Chip-enable signal. Active high. 4 - SENSOR_VP - GPI36, SENSOR_VP, ADC_H, ADC1_CH0, RTC_GPIO0 5 - SENSOR_VN - GPI39, SENSOR_VN, ADC1_CH3, ADC_H, RTC_GPIO3 6 - IO34 - GPI34, ADC1_CH6, RTC_GPIO4 7 - IO35 - GPI35, ADC1_CH7, RTC_GPIO5 8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
SD-CARD
MTDI
[HIGH]
[LOW]
internal voltage 3.3V
G.Martino
[DEFAULT]
Add a second inductor L4
Based on Arduino.cc design Released under the Creative Commons Attribution Share-Alike 4.0 License https://creativecommons.org/licenses/by-sa/4.0/

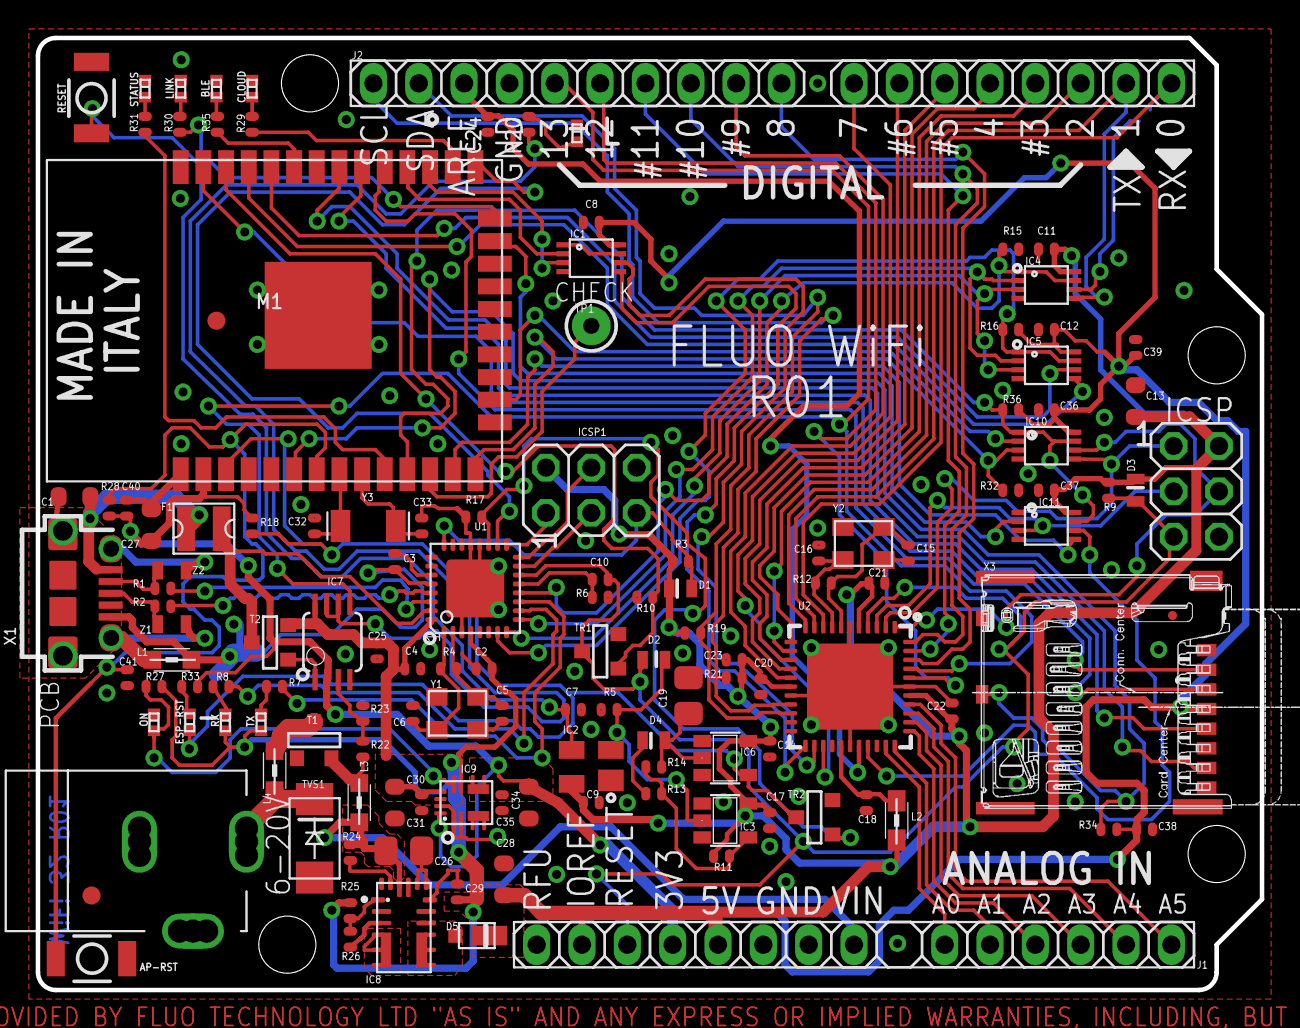
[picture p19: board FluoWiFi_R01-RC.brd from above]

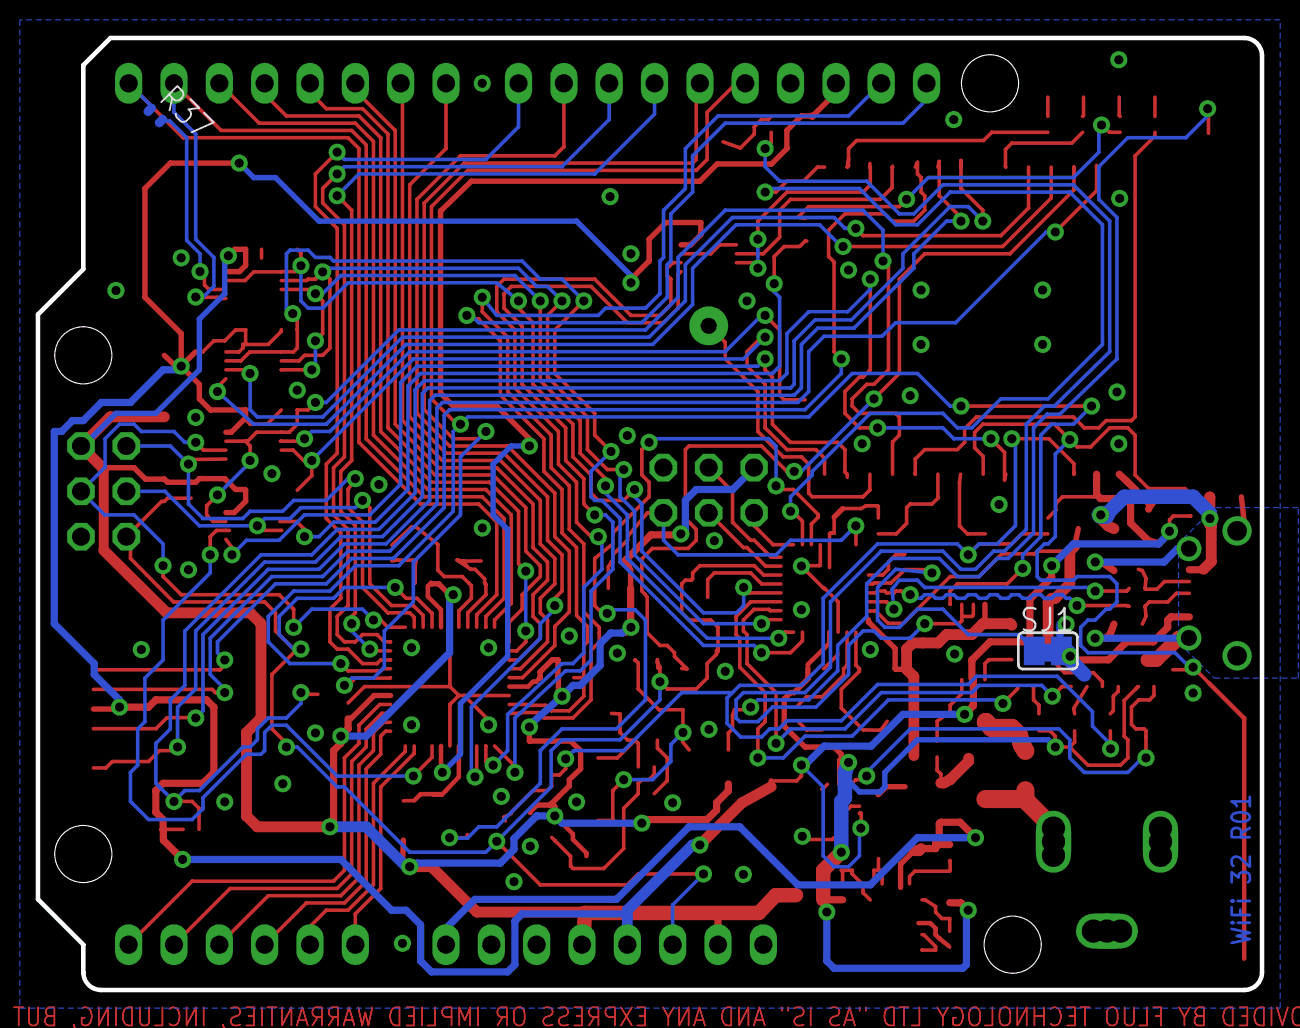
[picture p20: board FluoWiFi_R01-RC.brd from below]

Board: 2 copper layers, 68.6 x 53.3 mm, 138 parts (2 on the bottom side), 110 nets.

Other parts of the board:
DRILEGEND: DRILEGEND
FD1, FD3: FIDUCIALMOUNT; FIDUCIA-MOUNT
FD2: FIDUCIALMOUNT; MINI-FIDUCIAL
